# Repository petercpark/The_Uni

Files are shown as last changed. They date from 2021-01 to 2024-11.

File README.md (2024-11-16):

# The Uni Board
The uni-body split ortholinear keyboard for stenography, or the Uni for short. By Peter C Park. This is the pro micro version. I used KiCad Nightly Release so the kicad files are not compatible with older version.

Buy it now at [StenoKeyboards.com](https://www.stenokeyboards.com/).

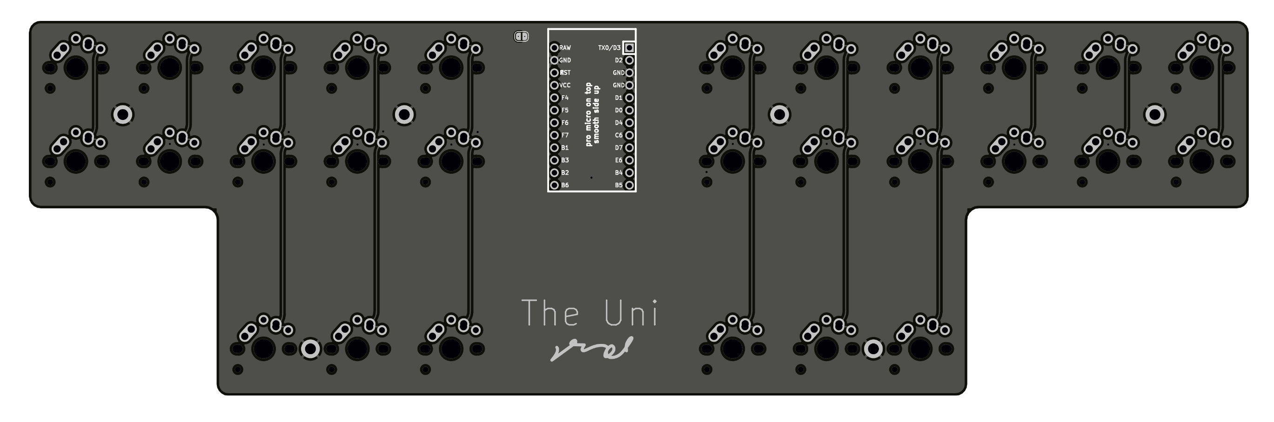
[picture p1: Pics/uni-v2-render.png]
pcb

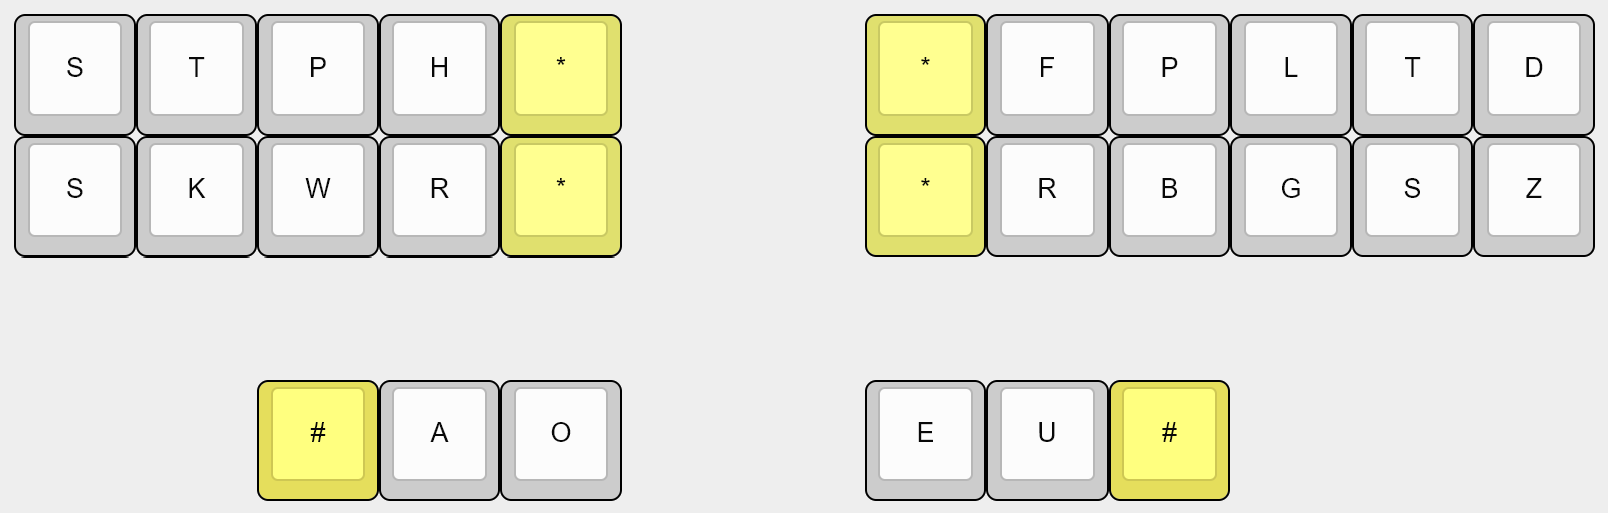
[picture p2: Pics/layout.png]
layout


## Product
If you are going DIY with this, here are the materials you need:
* The Uni PCB x 1 (diodes will come pre-assembled)
* Arduino Pro Micro x 1
* Switches x 28
* Keycaps x 28
* Willingness to solder x 1

If you want me to assemble here are the materials you need:
* money

## Arduino
The arduino you should use is the Pro Micro. You can also use other microcontrollers with same footprints such as the Elite C.

## Switches
Nearly any switch is compatible with the v2. The board has a footprint that accomodates for mx, alps, and choc v1 style switches.

## Keycaps
The best keycaps to use are the OEM R3 keycaps with one of the rows inverted to reduce the gap in the middle.
I used to recommend 3d printing your caps but OEM R3 caps are better. There are other flat keycaps for mx style switches at pimpmykeyboard.com called f10 keycaps. There is also a slightly less flatter version called the G20 keycaps on their store and people have used them for steno.
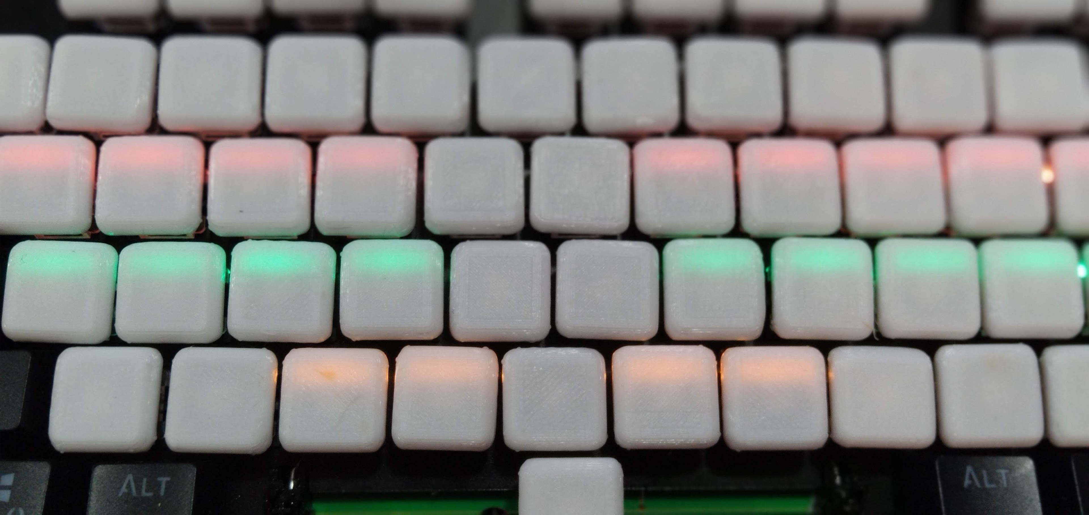
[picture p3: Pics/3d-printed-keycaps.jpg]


## Soldering
All you have to solder are the switches and pro micro if you get the pcb with the diodes assembled. If not you'll have to solder the smd diodes yourself. Check the BOM file for the necessary materials.

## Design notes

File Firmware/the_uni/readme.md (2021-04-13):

# The Uni

The Uni
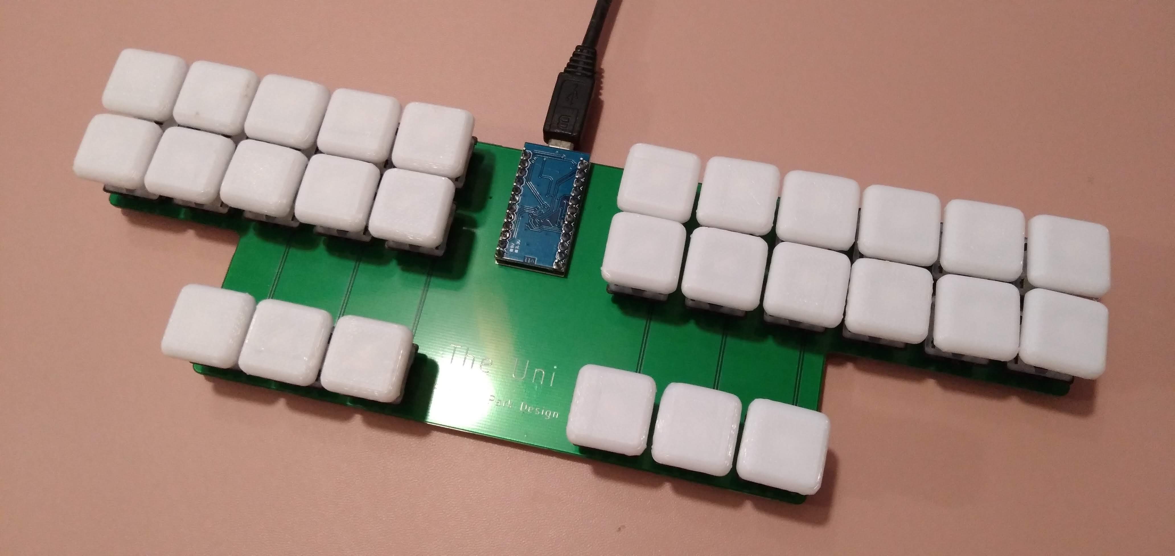
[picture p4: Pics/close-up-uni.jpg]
The Uni Closeup


A compact unibody split ortholinear keyboard made specifically for stenography.

-   Keyboard Maintainer: [Peter C. Park](https://github.com/petercpark)
-   Link to Keyboard Files: [The_Uni](https://github.com/petercpark/The_Uni)
-   Hardware Supported: The Uni v1 and v2 (pro micro or equivalent)
-   Hardware Availability: [website](https://www.stenokeyboards.com)
    
    Make example for this keyboard (after setting up your build environment):
    
    make the_uni:default
    
    See the [build environment setup](https://docs.qmk.fm/#/getting_started_build_tools) and the [make instructions](https://docs.qmk.fm/#/getting_started_make_guide) for more information. Brand new to QMK? Start with our [Complete Newbs Guide](https://docs.qmk.fm/#/newbs).

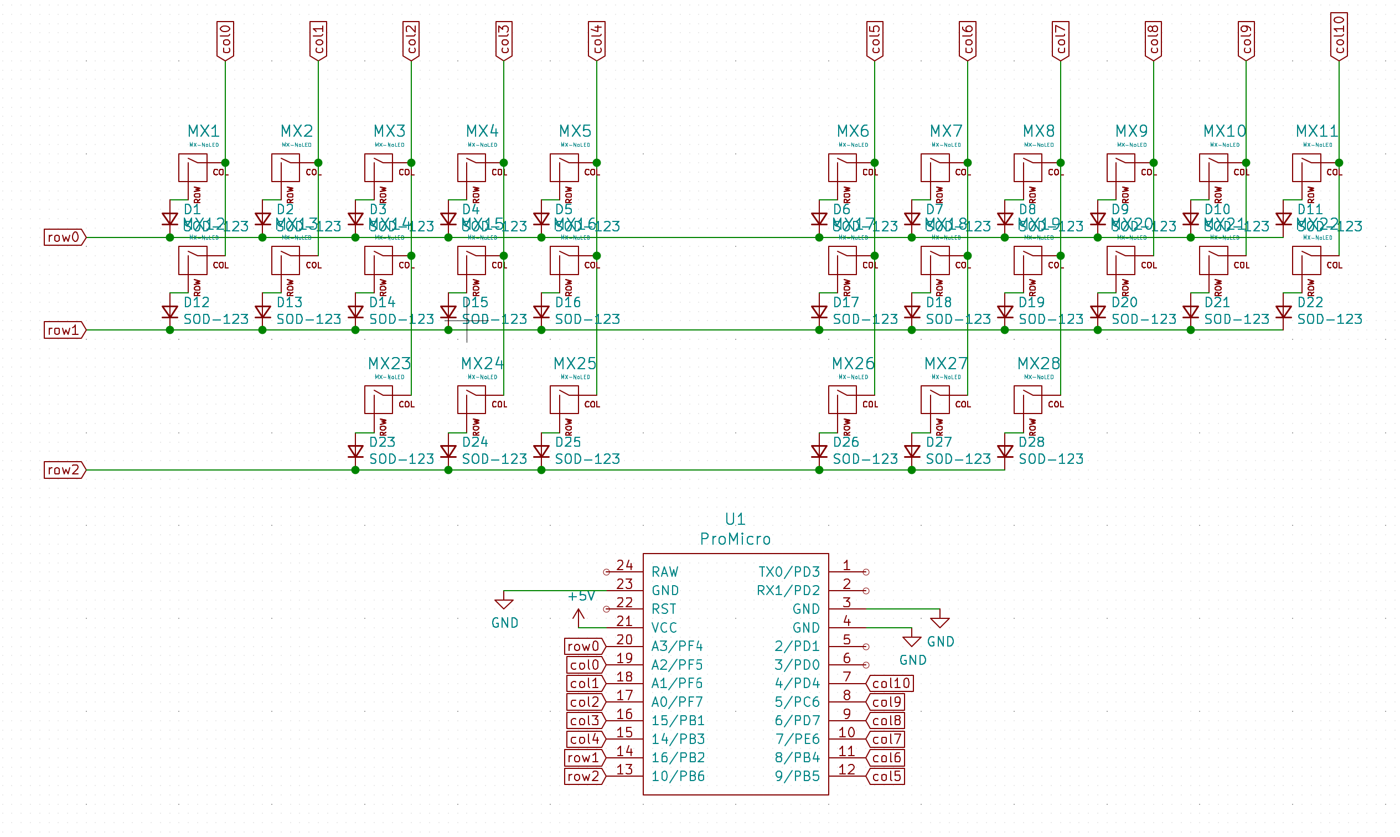
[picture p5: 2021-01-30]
Pics/schematic.png

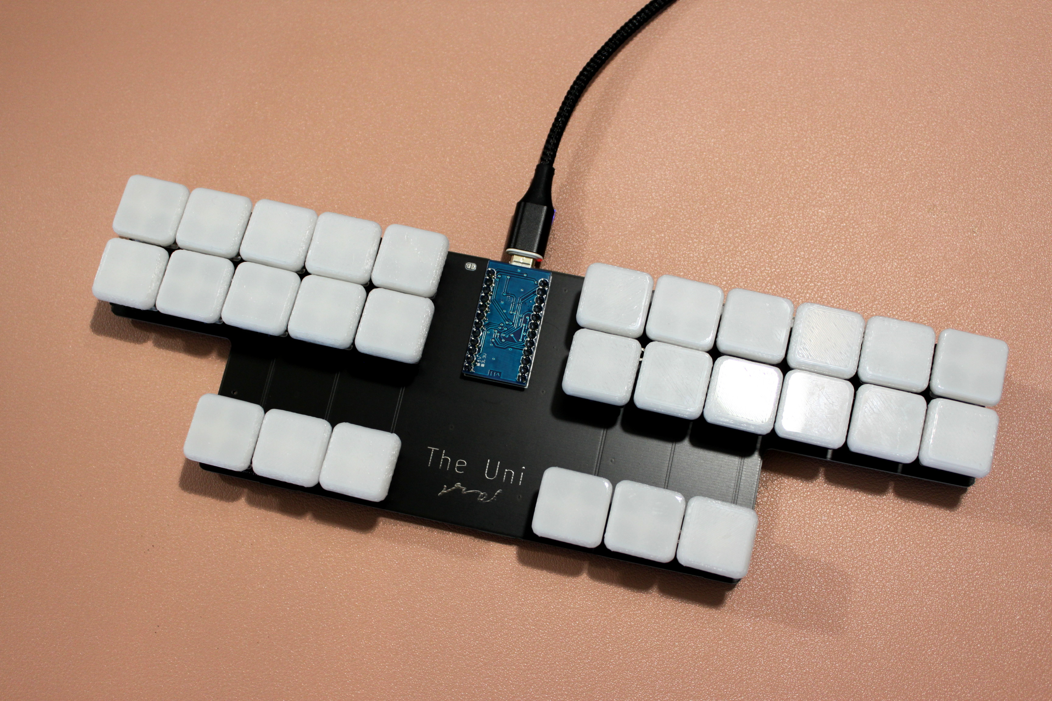
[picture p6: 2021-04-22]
Pics/uni v2/uni-v2.JPG

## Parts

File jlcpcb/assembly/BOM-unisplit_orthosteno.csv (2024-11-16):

Comment | Designator | Footprint | LCSC
SW_SPST | SW1 | SW_SPST_TL3342 | C318884
SOD-123 | D1,D10,D11,D12,D13,D14,D15,D16,D17,D18,D19,D2,D20,D21,D22,D23,D24,D25,D26,D27,D28,D3,D4,D5,D6,D7,D8,D9 | D_SOD123 | C81598

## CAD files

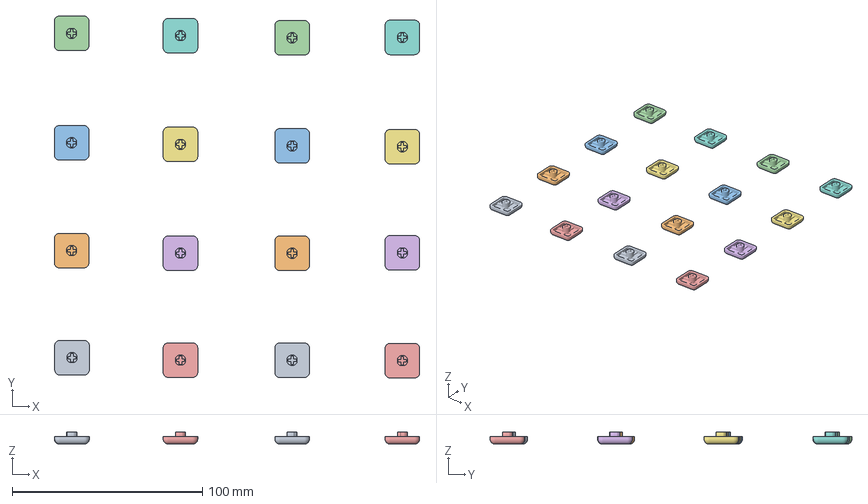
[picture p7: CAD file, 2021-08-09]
3d Printed Keycaps/print files/16 models 2.2.5 mx cap.3mf
191.8 x 190.0 x 6.50 mm
2.2.5-flatMX.stl
2.2.5-flatMX.stl(1)
2.2.5-flatMX.stl(2)
2.2.5-flatMX.stl(3)
2.2.5-flatMX.stl(4)
2.2.5-flatMX.stl(5)
2.2.5-flatMX.stl(6)
2.2.5-flatMX.stl(7)
2.2.5-flatMX.stl(8)
2.2.5-flatMX.stl(9)
2.2.5-flatMX.stl(10)
2.2.5-flatMX.stl(11)
2.2.5-flatMX.stl(12)
2.2.5-flatMX.stl(13)
2.2.5-flatMX.stl(14)
2.2.5-flatMX.stl(15)

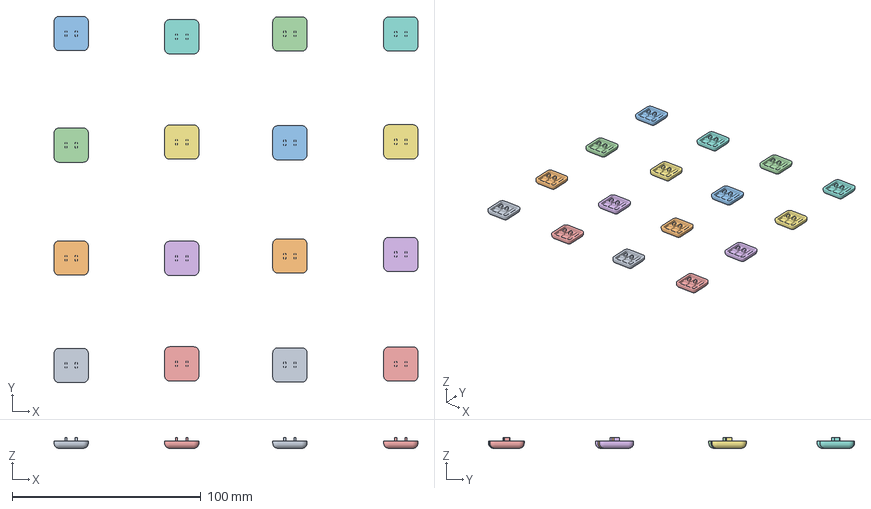
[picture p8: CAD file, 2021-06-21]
3d Printed Keycaps/print files/choc caps/16 models choc 1.1.3mf
192.9 x 194.1 x 5.69 mm
choc v1.1.stl(1)
choc v1.1.stl(2)
choc v1.1.stl(4)
choc v1.1.stl(3)
choc v1.1.stl(5)
choc v1.1.stl(6)
choc v1.1.stl(7)
choc v1.1.stl(8)
choc v1.1.stl(9)
choc v1.1.stl(10)
choc v1.1.stl(11)
choc v1.1.stl(12)
choc v1.1.stl(13)
choc v1.1.stl(14)
choc v1.1.stl(15)
choc v1.1.stl(16)

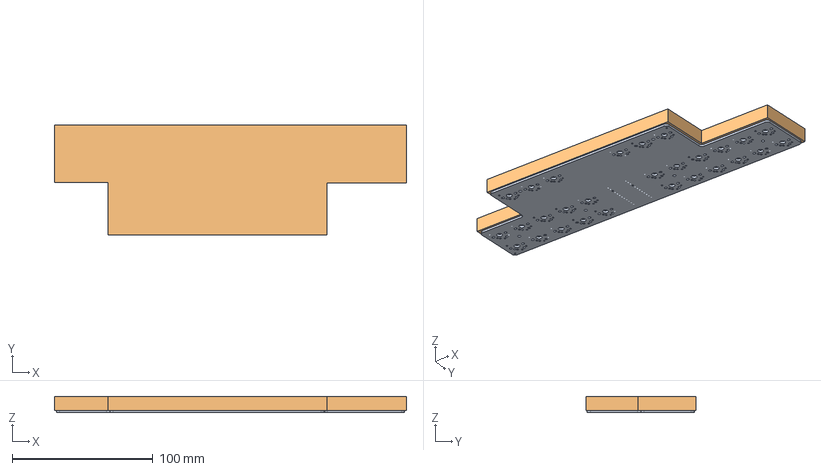
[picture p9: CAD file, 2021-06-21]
Case/3dp-full-case/try 2/case.FCStd
250.2 x 78.5 x 11.6 mm

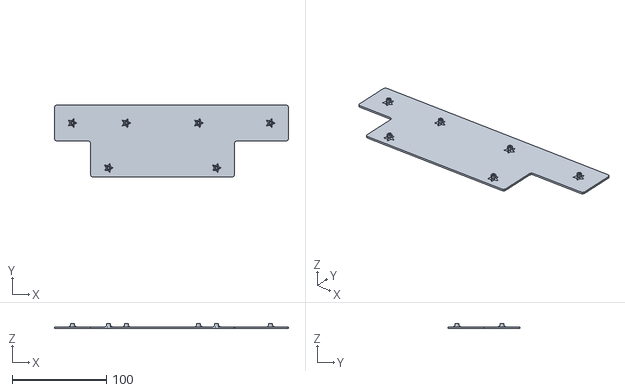
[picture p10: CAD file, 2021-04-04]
Case/backplate/3dp-back-plate/Uni Back Plate.stl
247.6 x 76.2 x 5.60

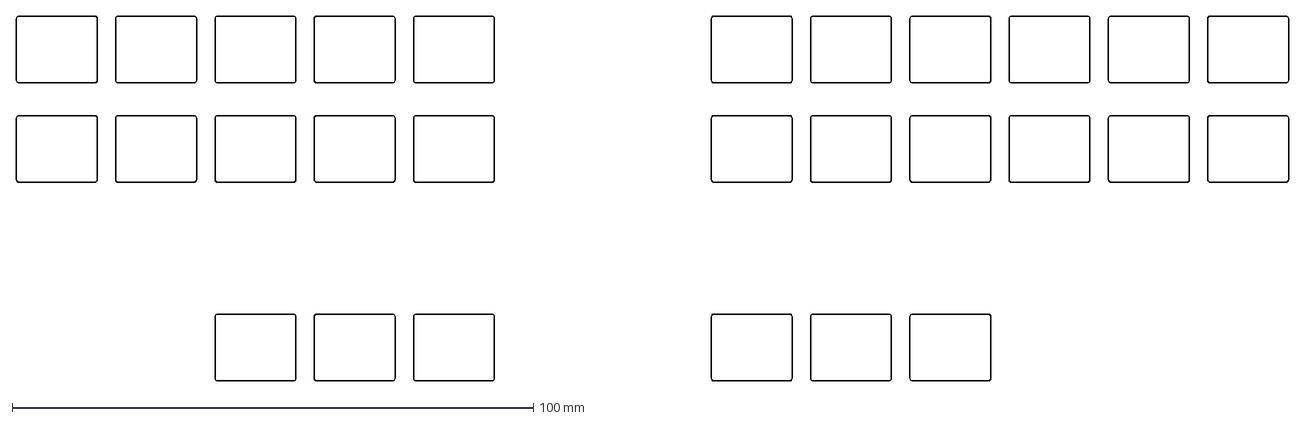
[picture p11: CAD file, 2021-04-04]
Case/switchplate/Alps/alps-plate.dxf
244.1 x 70.0 mm

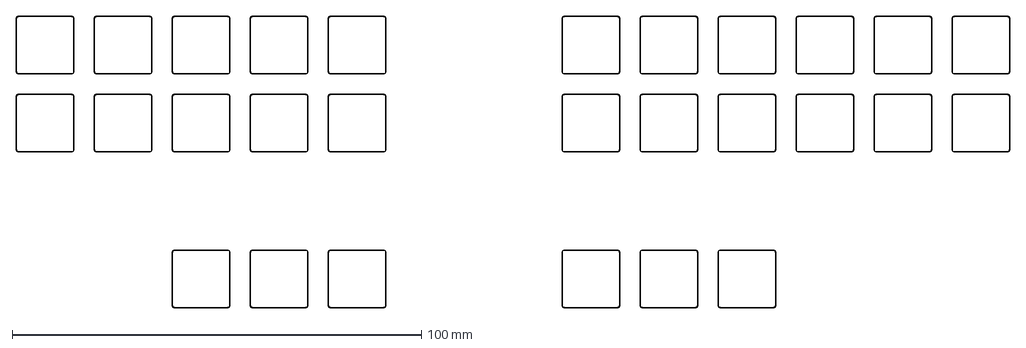
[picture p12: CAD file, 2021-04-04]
Case/switchplate/MX-Choc/mx-choc-plate.dxf
242.6 x 71.1 mm

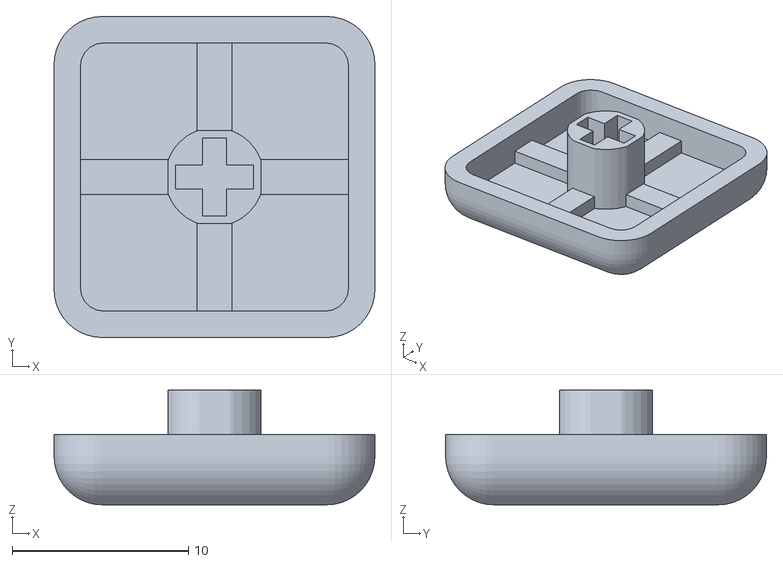
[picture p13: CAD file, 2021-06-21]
3d Printed Keycaps/print files/1 mx 2.2.5.stl
18.2 x 18.2 x 6.50

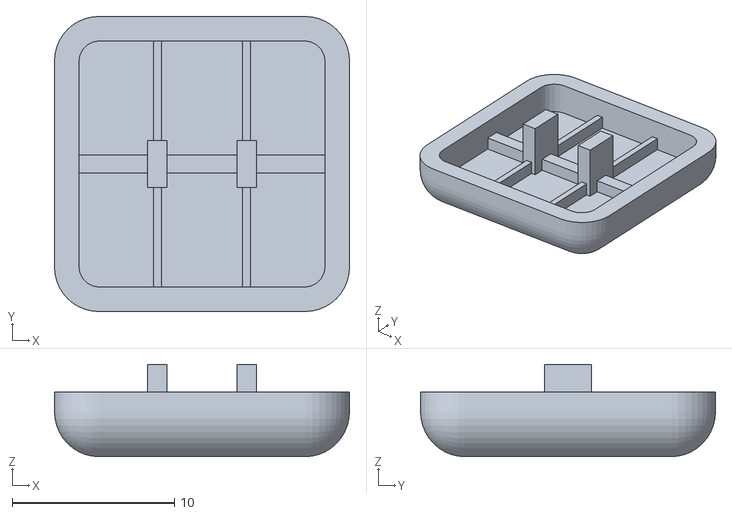
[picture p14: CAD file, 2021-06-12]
3d Printed Keycaps/print files/choc caps/choc v1.1.stl
18.2 x 18.2 x 5.69

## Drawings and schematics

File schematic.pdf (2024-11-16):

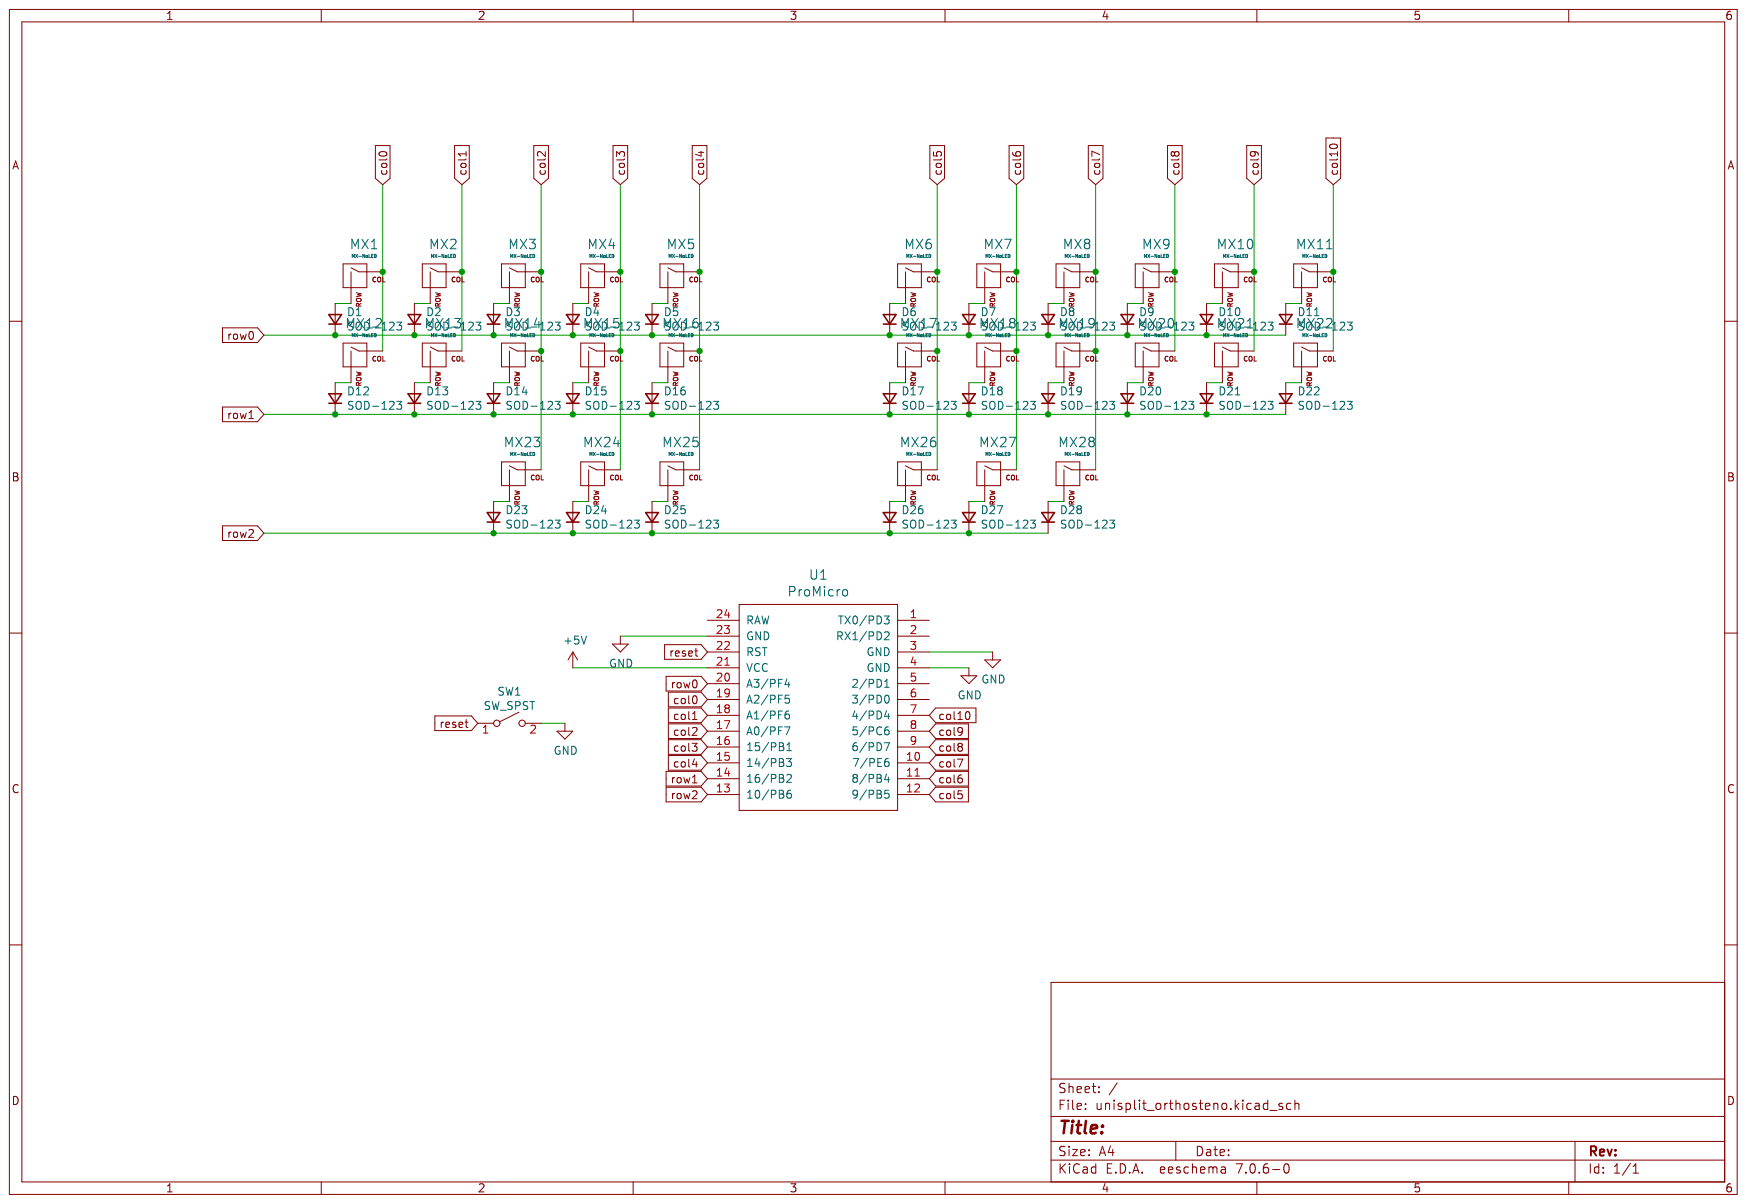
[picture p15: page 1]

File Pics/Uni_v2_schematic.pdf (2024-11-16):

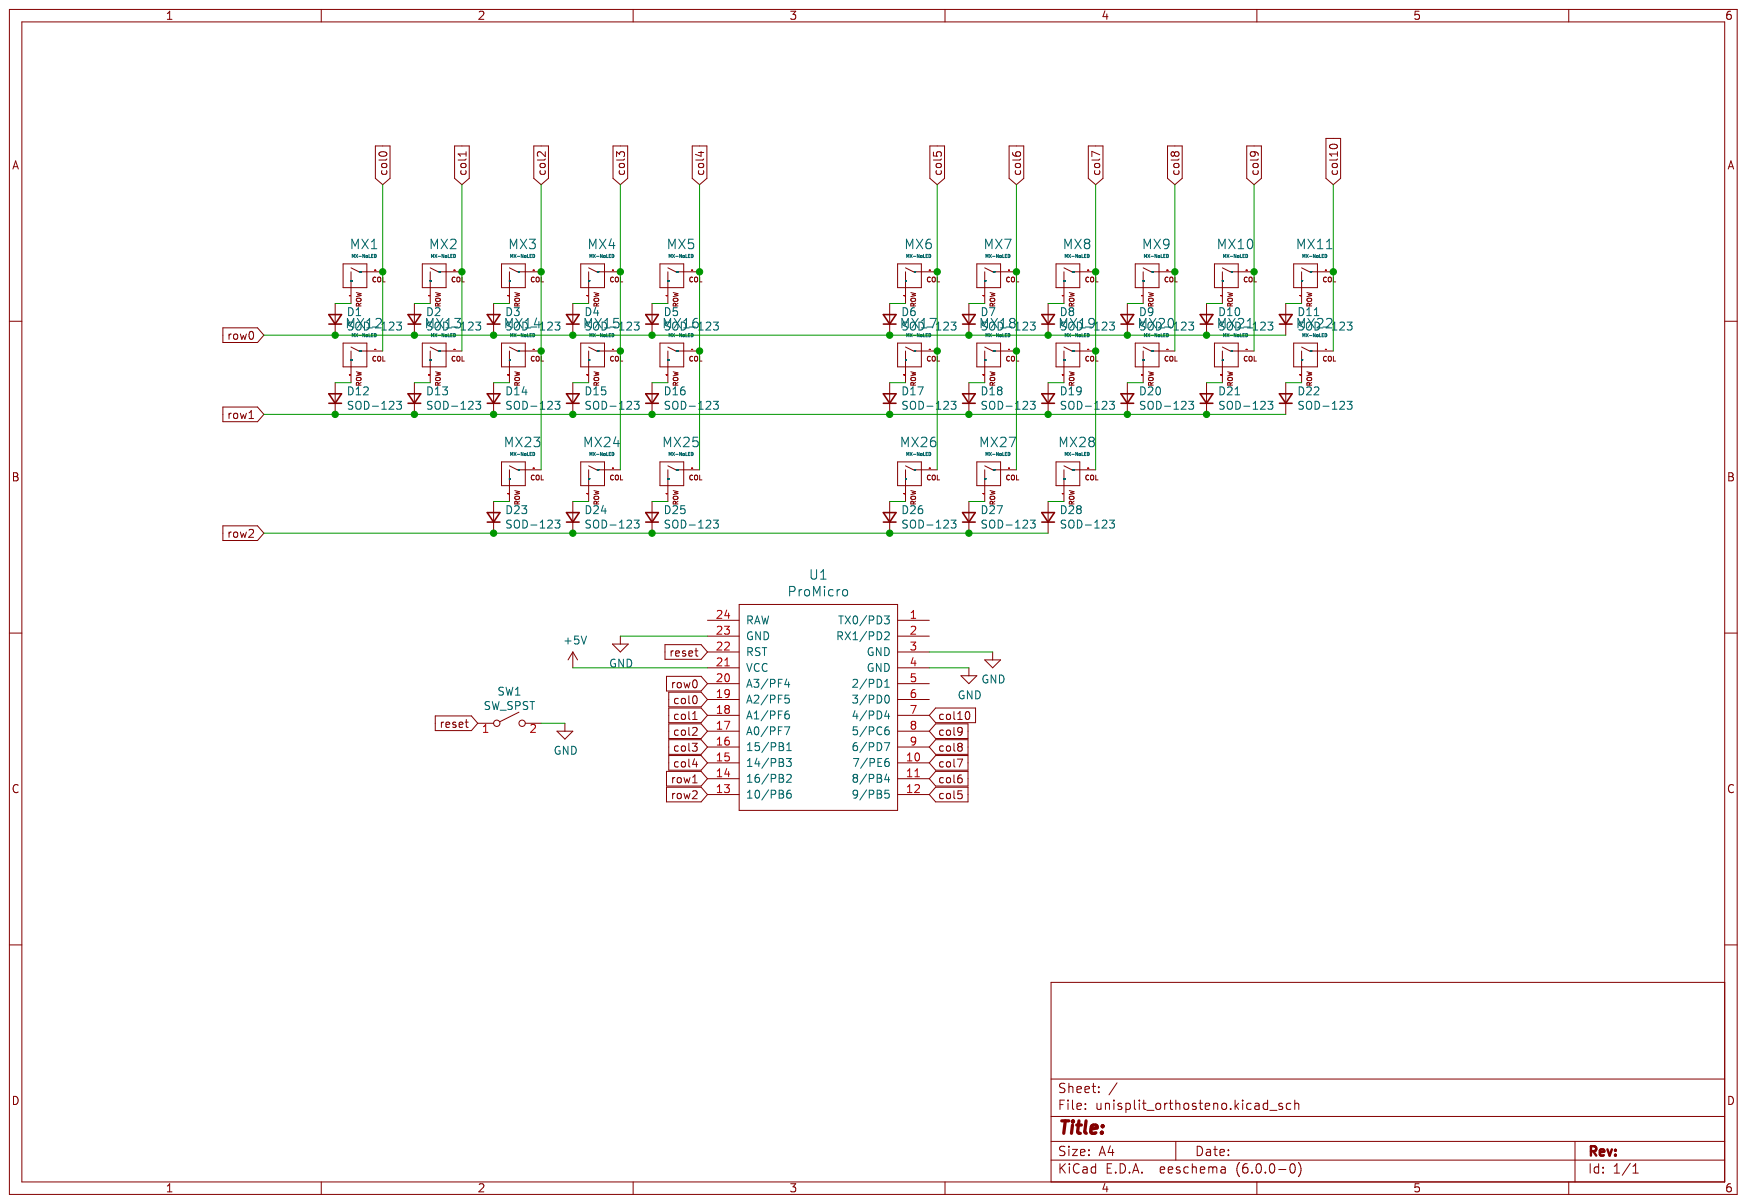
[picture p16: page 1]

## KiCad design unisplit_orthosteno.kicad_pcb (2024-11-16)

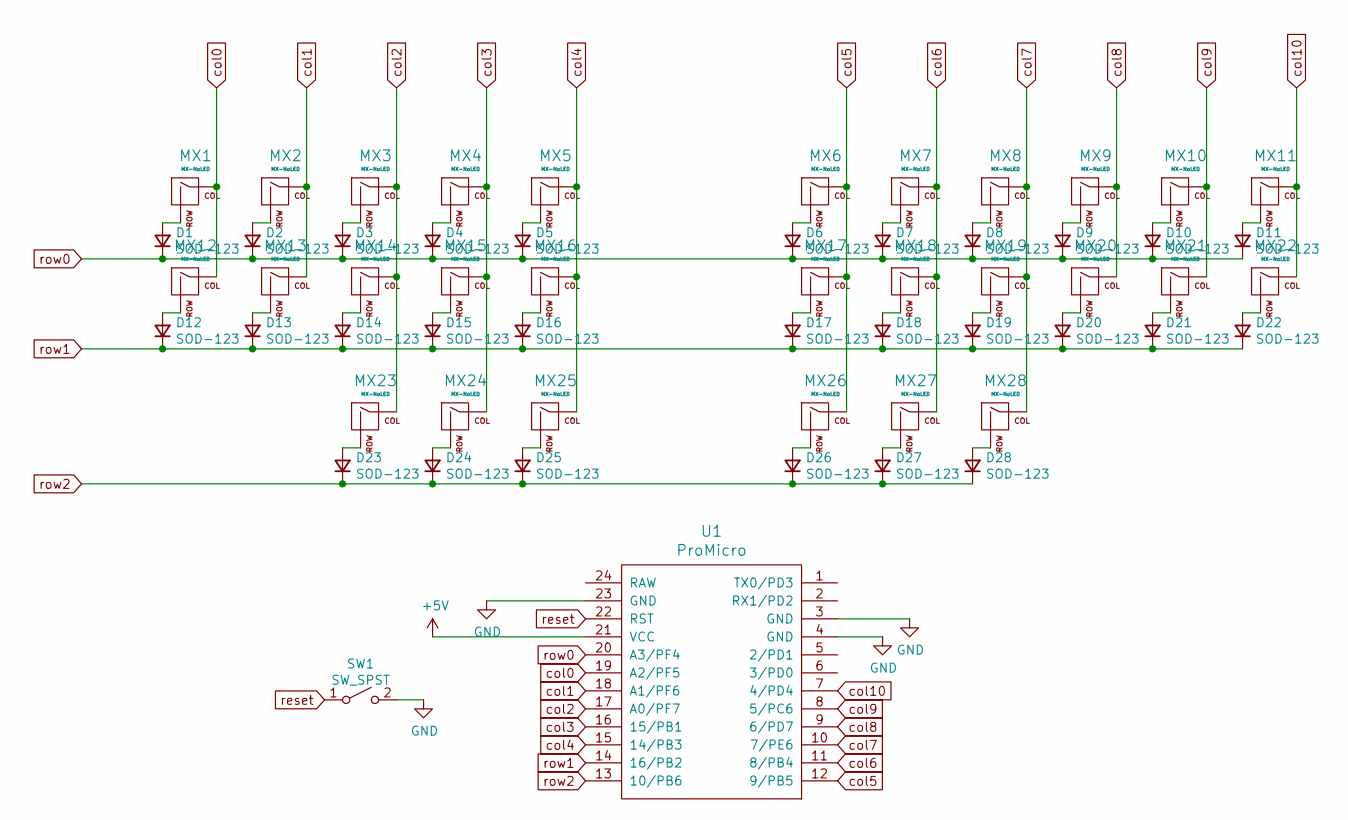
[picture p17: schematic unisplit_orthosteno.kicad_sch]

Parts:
D1, D2, D3, D4, D5, D6, D7, D8, D9, D10, D11, D12, D13, D15, D16, D17, D18, D19, D20, D21, D22, D23, D24, D25, D26, D27, D28: SOD-123; D_SOD123; LCSC C81598
D14: SOD-123; D_SOD123
MX1, MX2, MX3, MX4, MX5, MX6, MX7, MX8, MX9, MX10, MX11, MX12, MX13, MX14, MX15, MX16, MX17, MX18, MX19, MX20, MX21, MX22, MX23, MX24, MX25, MX26, MX27, MX28: MX-NoLED; MX-Alps-Choc-1U-NoLED
SW1: SW_SPST; SW_SPST_TL3342
U1: ProMicro; ArduinoProMicro

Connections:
+5V: U1.21 (VCC)
GND: SW1.2 (B), U1.3 (GND), U1.4 (GND), U1.23 (GND)
unnamed: D1.2 (A), MX1.2 (ROW)
unnamed: D2.2 (A), MX2.2 (ROW)
unnamed: D3.2 (A), MX3.2 (ROW)
unnamed: D4.2 (A), MX4.2 (ROW)
unnamed: D5.2 (A), MX5.2 (ROW)
unnamed: D6.2 (A), MX6.2 (ROW)
unnamed: D7.2 (A), MX7.2 (ROW)
unnamed: D8.2 (A), MX8.2 (ROW)
unnamed: D9.2 (A), MX9.2 (ROW)
unnamed: D10.2 (A), MX10.2 (ROW)
unnamed: D11.2 (A), MX11.2 (ROW)
unnamed: D12.2 (A), MX12.2 (ROW)
unnamed: D13.2 (A), MX13.2 (ROW)
unnamed: D14.2 (A), MX14.2 (ROW)
unnamed: D15.2 (A), MX15.2 (ROW)
unnamed: D16.2 (A), MX16.2 (ROW)
unnamed: D17.2 (A), MX17.2 (ROW)
unnamed: D18.2 (A), MX18.2 (ROW)
unnamed: D19.2 (A), MX19.2 (ROW)
unnamed: D20.2 (A), MX20.2 (ROW)
unnamed: D21.2 (A), MX21.2 (ROW)
unnamed: D22.2 (A), MX22.2 (ROW)
unnamed: D23.2 (A), MX23.2 (ROW)
unnamed: D24.2 (A), MX24.2 (ROW)
unnamed: D25.2 (A), MX25.2 (ROW)
unnamed: D26.2 (A), MX26.2 (ROW)
unnamed: D27.2 (A), MX27.2 (ROW)
unnamed: D28.2 (A), MX28.2 (ROW)
col0: MX1.1 (COL), MX12.1 (COL), U1.19 (A2/PF5)
col1: MX2.1 (COL), MX13.1 (COL), U1.18 (A1/PF6)
col2: MX3.1 (COL), MX14.1 (COL), MX23.1 (COL), U1.17 (A0/PF7)
col3: MX4.1 (COL), MX15.1 (COL), MX24.1 (COL), U1.16 (15/PB1)
col4: MX5.1 (COL), MX16.1 (COL), MX25.1 (COL), U1.15 (14/PB3)
col5: MX6.1 (COL), MX17.1 (COL), MX26.1 (COL), U1.12 (9/PB5)
col6: MX7.1 (COL), MX18.1 (COL), MX27.1 (COL), U1.11 (8/PB4)
col7: MX8.1 (COL), MX19.1 (COL), MX28.1 (COL), U1.10 (7/PE6)
col8: MX9.1 (COL), MX20.1 (COL), U1.9 (6/PD7)
col9: MX10.1 (COL), MX21.1 (COL), U1.8 (5/PC6)
col10: MX11.1 (COL), MX22.1 (COL), U1.7 (4/PD4)
reset: SW1.1 (A), U1.22 (RST)
row0: D1.1 (K), D2.1 (K), D3.1 (K), D4.1 (K), D5.1 (K), D6.1 (K), D7.1 (K), D8.1 (K), D9.1 (K), D10.1 (K), D11.1 (K), U1.20 (A3/PF4)
row1: D12.1 (K), D13.1 (K), D14.1 (K), D15.1 (K), D16.1 (K), D17.1 (K), D18.1 (K), D19.1 (K), D20.1 (K), D21.1 (K), D22.1 (K), U1.14 (16/PB2)
row2: D23.1 (K), D24.1 (K), D25.1 (K), D26.1 (K), D27.1 (K), D28.1 (K), U1.13 (10/PB6)

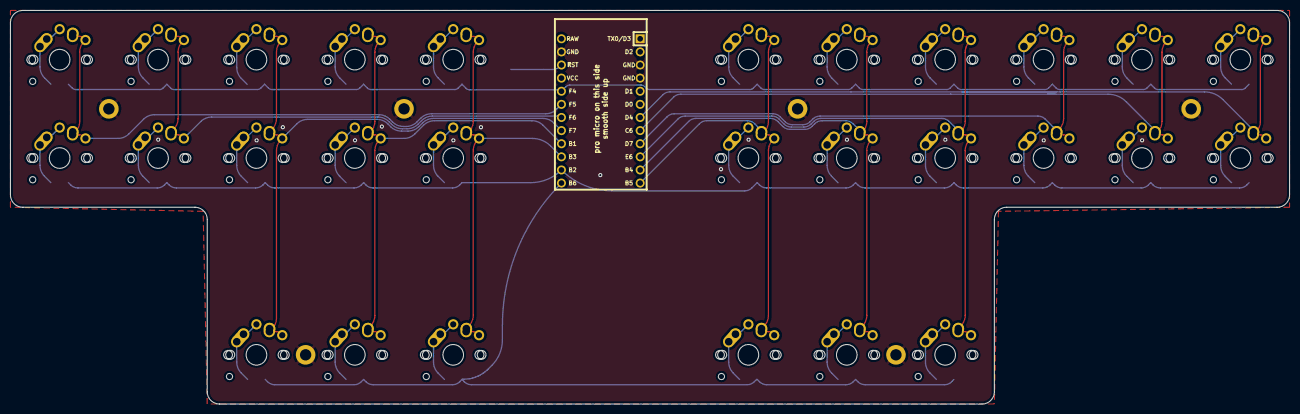
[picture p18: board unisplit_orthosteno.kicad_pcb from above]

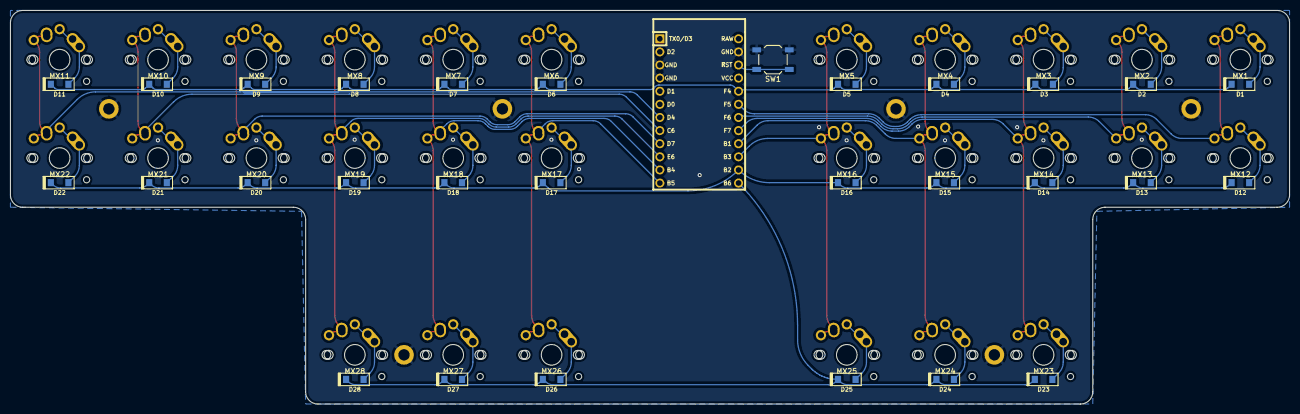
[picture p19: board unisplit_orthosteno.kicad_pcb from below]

Board: 2 copper layers, 247.6 x 76.2 mm, 58 parts (30 on the bottom side), 44 nets.

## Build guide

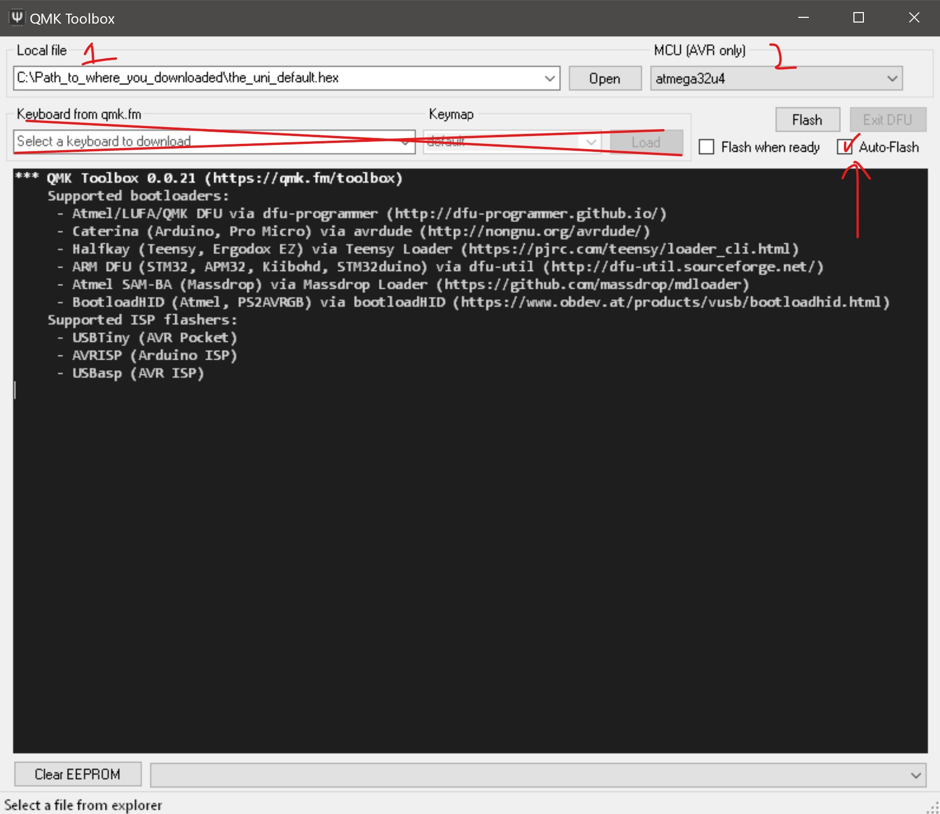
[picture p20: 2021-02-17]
Pics/qmk-toolbox-setup.jpg

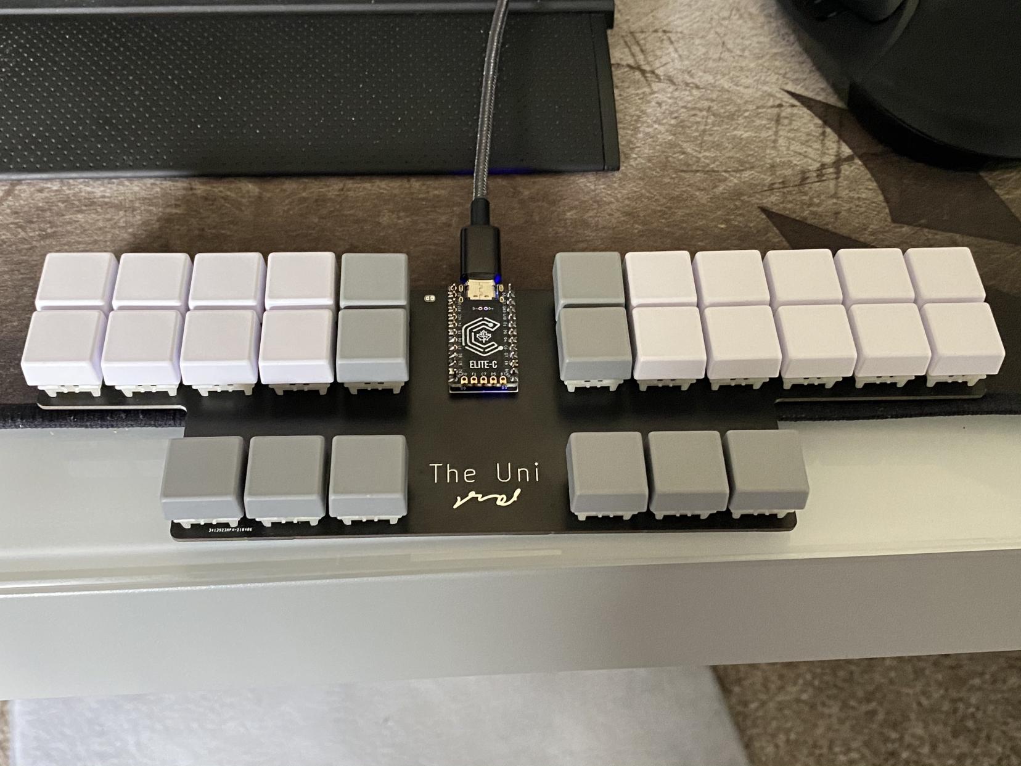
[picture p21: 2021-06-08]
Pics/uni build pics/Akikaze#2771.jpg

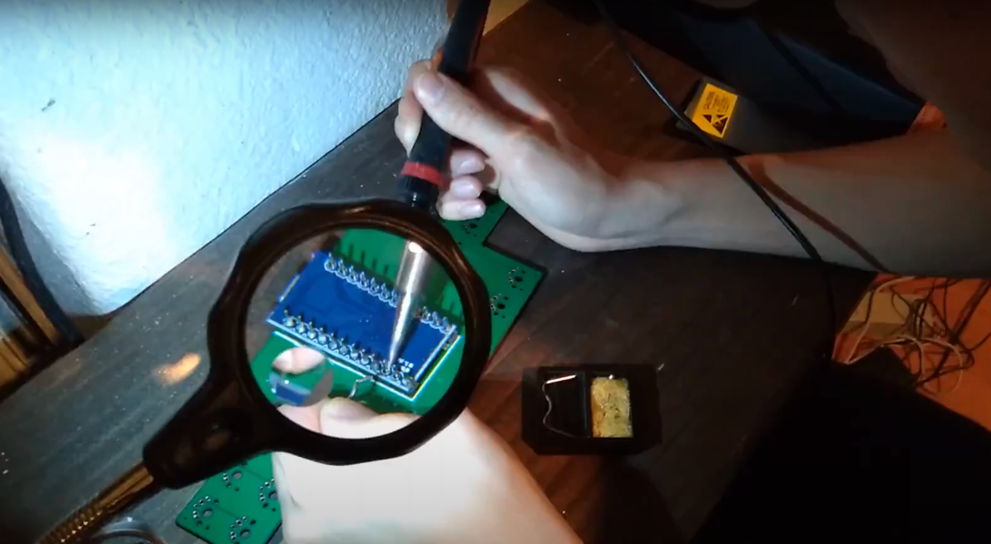
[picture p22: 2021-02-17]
Pics/soldering-pro-micro.jpg

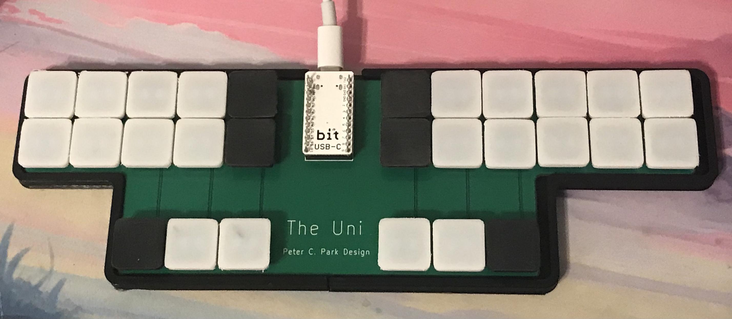
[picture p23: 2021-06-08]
Pics/uni build pics/Ewen#5381.jpg

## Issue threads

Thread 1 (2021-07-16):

Need to Specify the Type of Diodes

Quisette, 2021-07-16:
Recently I’ve self-printed some PCBs of your model,
but I have not found any description about the type of the diode, including the voltage. This makes me unable to specify which diode to use.
If able, please provide the specific diodes you use when soldering your pcbs.

Thanks

petercpark, 2021-07-16:
Most SOD-123 diodes commonly used in keyboards work. I use SM4007PL but 1N4148W also works. You can find the LCSC part number of the diode I use in the [BOM](https://github.com/petercpark/The_Uni/blob/main/Gerbers/v2/unisplit_orthosteno_bom.csv)

Closed 2021-07-17.

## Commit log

2021-01-21 add sumodules (symbols and footprints)
2021-01-21 symbols and footprints
2021-01-21 ai03 library import for symbols and footprints
    [unisplit_orthosteno.sch]
2021-01-21 add keebio library
    [unisplit_orthosteno.sch]
2021-01-21 all components and footprints added
2021-01-21 finally found pro micro symbol from keebio
    [unisplit_orthosteno.sch]
2021-01-21 assign footprints and do some organizing
    [unisplit_orthosteno.kicad_pcb, unisplit_orthosteno.sch]
2021-01-22 finished routing but possible problem in column 3 and 4 which I asked and reddit
    [plate.dxf, unisplit_orthosteno.kicad_pcb, unisplit_orthosteno.sch]
2021-01-23 re route and change layout per suggestions from plover discord
    [plate.dxf, unisplit_orthosteno.kicad_pcb, unisplit_orthosteno.sch]
2021-01-23 generate gerbers
    [unisplit_orthosteno-B_Cu.gbl, unisplit_orthosteno-B_Mask.gbs, unisplit_orthosteno-B_Paste.gbp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]
2021-01-23 finalize gerbers and create bom and place files for jlcpcb
    [unisplit_orthosteno-BOM.xlsx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]
2021-01-24 add uni name on the pcb
    [unisplit_orthosteno-B_Cu.gbl, unisplit_orthosteno-B_Mask.gbs, unisplit_orthosteno-B_SilkS.gbo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]
2021-01-24 still working on making case files, but added a read me
    [The Uni board plate cut.stl]
2021-01-26 create rough design of case and plate, but it is not the correct measurments
    [The Uni board plate cut.stl, The Uni board top plate.stl]
2021-01-30 update case files, now the cases should be okay, case may be a bit tight so scaling up like 0.001 percent might help when 3d printing it
    [The Uni board bottom.stl, The Uni board full case.stl, The Uni board middle.stl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]
2021-01-30 add image of 3d printed keycaps
2021-01-31 update case files by giving a little bit of clearance
    [The Uni board bottom.stl, The Uni board full case.stl, The Uni board middle.stl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]
2021-02-17 add guide folder
    [case border.stl]
2021-02-17 soldering pro micro picture
2021-02-20 add image of keycaps and change case
    [case border.stl, full case.stl, middle layer.stl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]
2021-02-24 revert back to slightly tighter case fit, and fix misalignment
    [unisplit_middle.kicad_pcb]
2021-02-24 stl files for case revert back to slightly tighter
    [full case.stl, middle layer.stl]
2021-02-24 make case/sleeve fit exactly the same as the pcb, no tolerances
    [bottom layer.stl, bottom.stl, full case.stl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]
2021-02-25 add files for keycaps
    [2.1.5-flatMX.stl]
2021-02-26 add split case files for easy printing
    [Left - Uni Case (Split).stl, Right - Uni Case (Split).stl, unisplit_orthosteno.kicad_pcb]
2021-02-26 add case-info.md file
2021-03-03 add mounting holes to the uni pcb, also create a back plate folder in cases folder
    [back-plate.kicad_pcb, mx-alps-plate.dxf, mx-plate.dxf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]
2021-03-04 back plate move to reference folder
    [2.1.6-flatMX.stl]
2021-03-08 backplate design
    [back-plate.kicad_pcb]
2021-03-08 add back plate screen shot
    [back-plate.kicad_pcb]
2021-03-10 add rubber feet placement image
    [2.1.6-flatMX.stl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]
2021-03-31 curvy trace and add reset
    [unisplit_orthosteno.kicad_pcb, unisplit_orthosteno.kicad_sch, unisplit_orthosteno.sch]
2021-04-01 save backplate file
    [back-plate.kicad_pcb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]
2021-04-01 get rid of backplate
    [back-plate-B_Cu.gbl, back-plate-B_Mask.gbs, back-plate-B_SilkS.gbo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]
2021-04-01 add backplate
    [back-plate-B_Cu.gbl, back-plate-B_Mask.gbs, back-plate-B_Silkscreen.gbo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]
2021-04-01 change rubber feet placement in guide
    [unisplit_orthosteno-B_Cu.gbl, unisplit_orthosteno-B_Mask.gbs, unisplit_orthosteno-B_SilkS.gbo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]
2021-04-02 make a no overlap mx-alp-choc footprint
    [2.1.6-flatMX.stl]
2021-04-04 create plate and case designs
    [Left - Uni Case (Split).stl, Right - Uni Case (Split).stl, Uni Back Plate.stl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]
2021-04-06 fix fatal diode error
    [Uni-full-case.stl, full-case-bezels.kicad_pcb, full-case-inner.kicad_pcb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]
2021-04-08 plate stuff
    [mx-choc-plate.kicad_pcb]
2021-04-09 add tooling and order number
    [unisplit_orthosteno-B_Cu.gbl, unisplit_orthosteno-B_Mask.gbs, unisplit_orthosteno-B_Silkscreen.gbo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]
2021-04-13 3dp case with ceiling and fillet
    [2u_2.1.5.stl, Uni-full-case.stl]
2021-04-13 add more mounting holes
    [unisplit_orthosteno.kicad_pcb]
2021-04-15 get rid of extra nuisance mounting holes
    [unisplit_orthosteno.kicad_pcb]
2021-04-20 update keycap, also add some photos
    [2.1.6-flatMX.stl]
2021-04-27 update gerbers.
    [2.2.0-flatMX.stl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]
2021-05-15 update commit
    [2.2.1-flatMX.stl, 2.2.2-flatMX.stl, 2.2.3-flatMX.stl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]
2021-05-28 gerbers and backplate
    [2.1.5-flatMX.stl, 2.1.6-flatMX.stl, 2.1.7-flatMX.stl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]
2021-06-04 step file
    [back-plate-B_Cu.gbl, back-plate-B_Mask.gbs, back-plate-B_Silkscreen.gbo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]
2021-06-12 make choc keycap model
    [choc v1.1.stl]
2021-06-21 caps update
    [16 CE3_choc v1.1.3mf, 2.2.4-flatMX.stl, 2.2.5-flatMX.stl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]
2024-11-16 add schematic
    [BOM-unisplit_orthosteno.csv, mx-choc-plate.kicad_pcb, unisplit_orthosteno-BOM.xlsx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]
